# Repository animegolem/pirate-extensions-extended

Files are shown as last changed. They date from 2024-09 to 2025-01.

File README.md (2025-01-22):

 # pirate-extensions-extended
Adapting AudioGroupCologne's Adaptions to the PIRATE In-Ear Microphones for electret micorphones and general headphone hobbyist use.

## Description
This repository contains additional supplementary materials for adapted in-ear microphones [1], based on the PIRATE microphones design by Denk et al. [2]

I strongly recommend reading both linked papers because this is just boiling down and stealing that work. o7 

## Contents

[Bill of Materials](Bill_of_Materials.md)

[Build Instructions](build_guide.md)

[Pirate Models](pirate-models)

The updated molds and guide tool support 3mm and 4mm electret capsules. Additionally, the original pirate extensions support a 3mm MEMS microphone. Note that only the top mold has been updated and the original center and base mold are still required. 

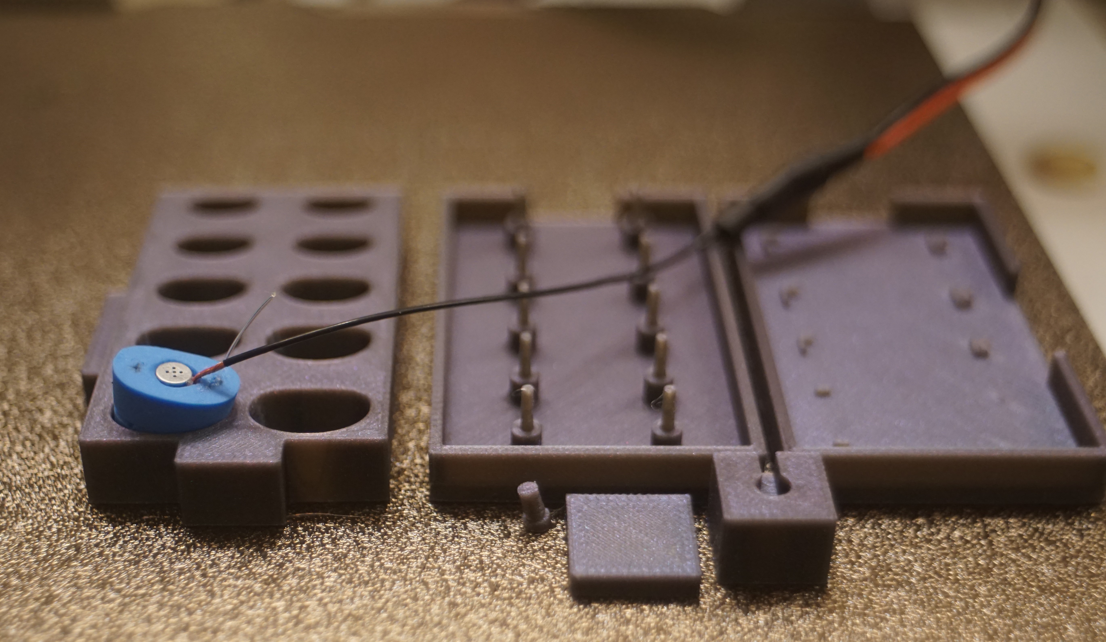
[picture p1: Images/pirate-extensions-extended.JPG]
4mm electret


For a rough guide on how to use the microphones and create a personal target please see the [usage guide](usage_guide/usage_guide.md). Please expect the results to be confusing and problematic if you start this project. 

I've also setup a [graphtool](https://animegolem.github.io/) as an example of how this data may look once collected. This data should not be compared to any other rig and extreme caution should be used when drawing any conclusions. 

## REFERENCES

[1] D. Bau, O. Moschner, C. Poerschmann "Adapting the PIRATE Design for Cost-Effective In-Ear Microphones", Proceedings of the 50th DAGA, Hannover, Mar. 2024

[2] F. Denk, F. Brinkmann, A. Stirnemann, and B. Kollmeier, “The PIRATE: an anthropometric earPlug with exchangeable microphones for Individual Reliable Acquisition of Transfer functions at the Ear canal entrance”, Proceedings of the 45th DAGA, Rostock, Mar. 2019

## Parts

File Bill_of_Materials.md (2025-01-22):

## Bill of Materials 

### Ear Plugs 

1. A reasonably competent 3D printer is required in order to create the mold. Alternatively you could use a print service. 

2. A two part, kneadable silicone. This should be between shore 40-65a so it is soft enough to form a perfect seal but firm enough that it will not deform and vary placement. The original paper suggests 55A is ideal if possible.

* [I've successfully used the following (40a) but harder would be more ideal.](https://www.amazon.com/dp/B09TGKS4KY)

* [Needs to be tested but likely better. (50a)](https://micromark.com/products/micro-mark-rtv-silicone-mold-putty-50-hard)

3. Monofilament fishing line, .4mm or greater.

4. Super Glue

5. A needle or similar to make holes in the finished plug

6. Straight razor to clean up demolded plug. 
 
### Microphone

1. 3-10ft Well shielded Microphone cable (I've used Canare L-2T2S)

2. Shrink Wrap or Electrical Tape 

3. 3mm/4mm Electret or 3mm MEMS microphone with a relatively flat and extended response. 

* see [capsule_testing](capsule_testing.md).

3. Male 3.5mm connector

4. 2 Part Epoxy or Thick Gel Super Glue
    
5. Apple dongle or equivalent

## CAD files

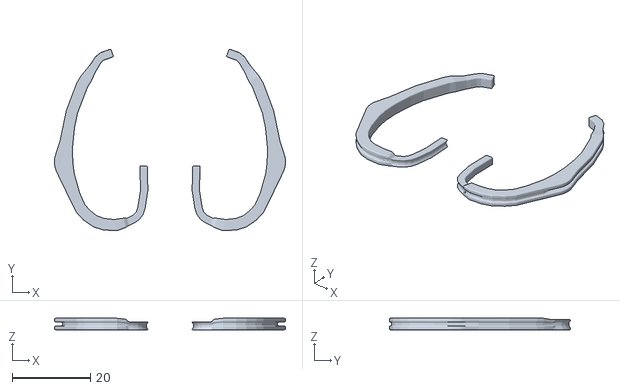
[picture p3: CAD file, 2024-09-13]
pirate-models/original-pirate-extensions/earhooks/earhooks_large.stl
59.1 x 46.4 x 2.95

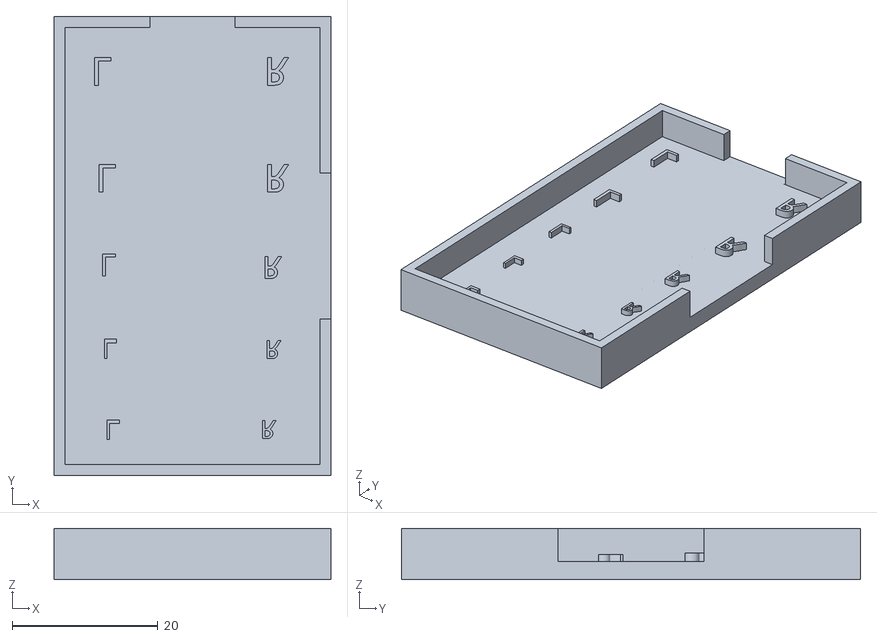
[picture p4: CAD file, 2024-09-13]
pirate-models/original-pirate-extensions/molds/pirate_form_bottom.stl
38.0 x 63.0 x 7.00

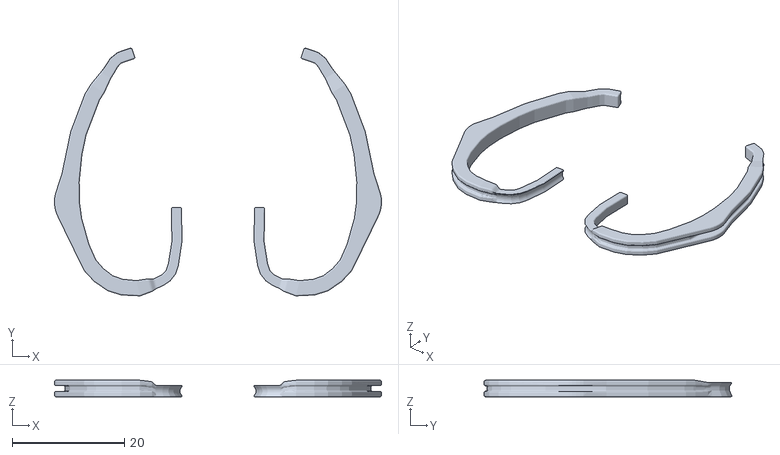
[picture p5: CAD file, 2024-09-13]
pirate-models/original-pirate-extensions/earhooks/earhooks_medium.stl
58.2 x 44.1 x 2.95

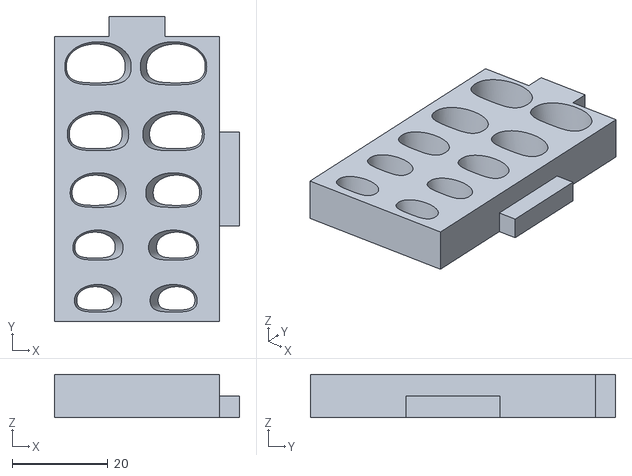
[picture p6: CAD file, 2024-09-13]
pirate-models/original-pirate-extensions/molds/pirate_form_middle.stl
38.8 x 63.8 x 9.00

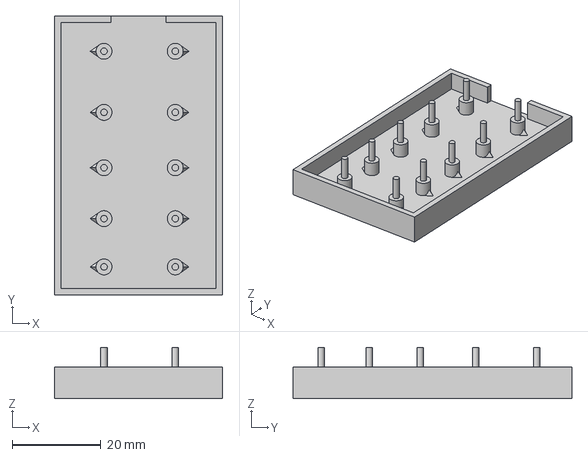
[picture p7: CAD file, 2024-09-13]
pirate-models/pirate_form_top_electret.step
38.0 x 63.0 x 11.6 mm

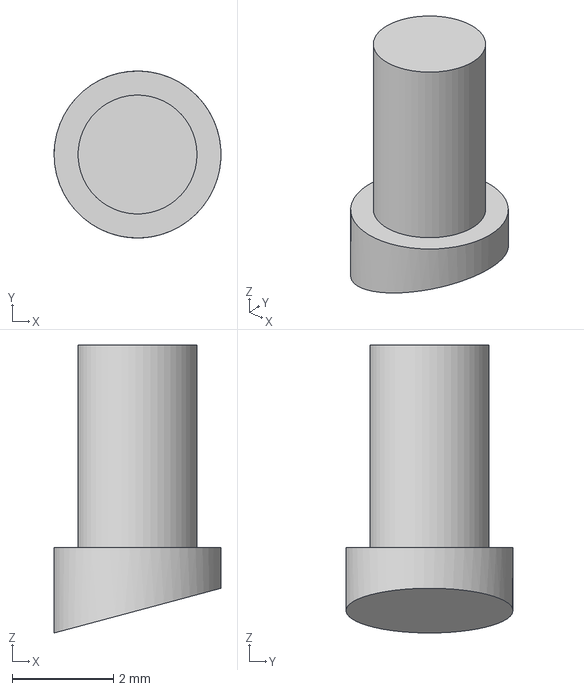
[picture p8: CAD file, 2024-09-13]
pirate-models/Electret Standoff -15% Tilt.step
3.30 x 3.30 x 5.69 mm

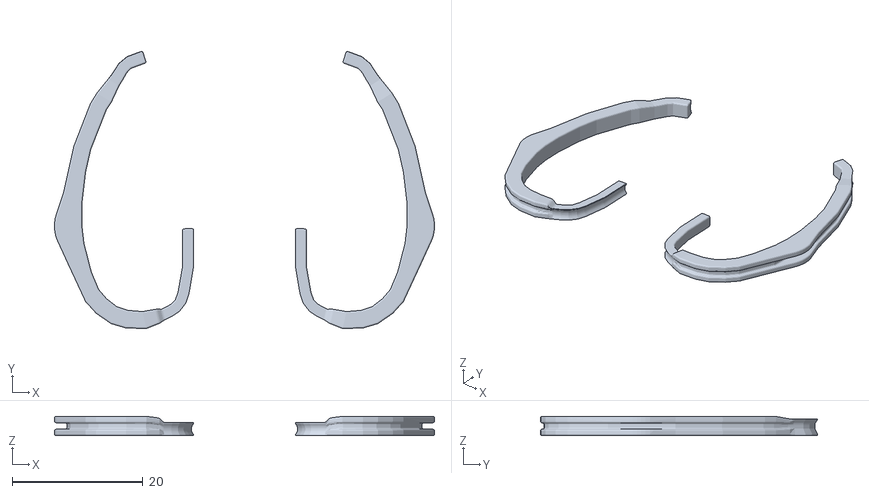
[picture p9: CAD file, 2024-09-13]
pirate-models/original-pirate-extensions/earhooks/earhooks_small.stl
58.1 x 42.3 x 2.95

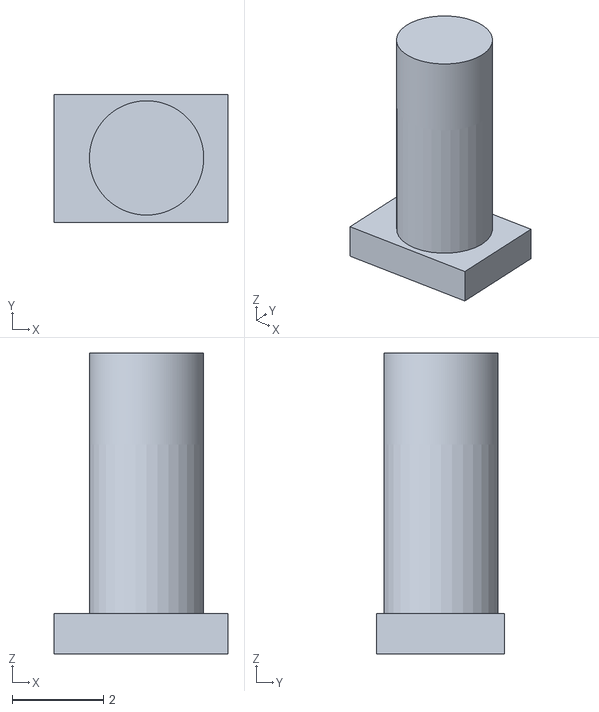
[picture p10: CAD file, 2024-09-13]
pirate-models/original-pirate-extensions/molds/pirate_mems_holder.stl
3.80 x 2.80 x 6.59

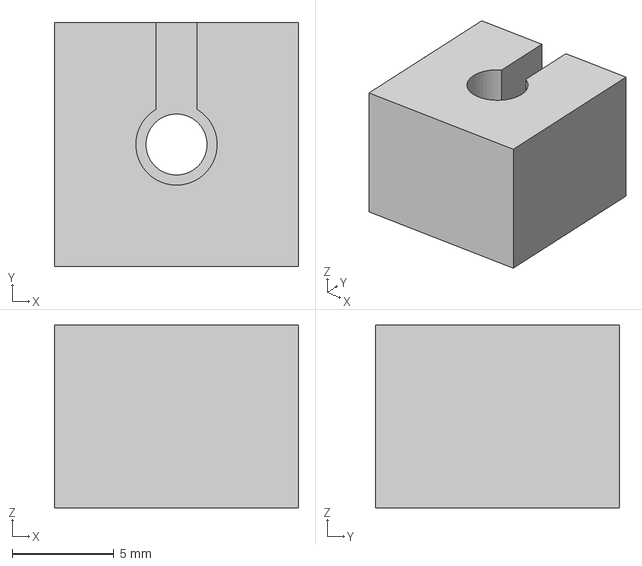
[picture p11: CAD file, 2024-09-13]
pirate-models/Gluing Guide Tool - Base.step
12.0 x 12.0 x 9.00 mm

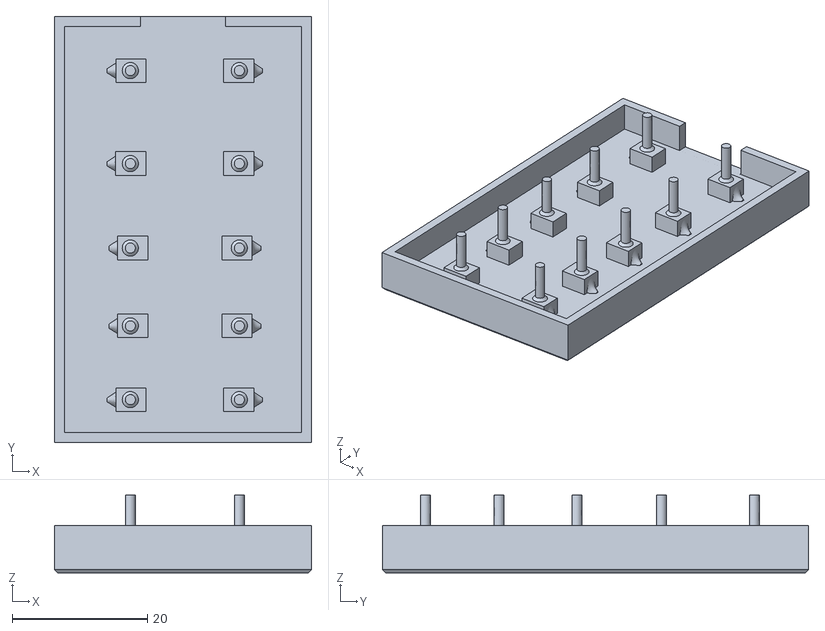
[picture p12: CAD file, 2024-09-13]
pirate-models/original-pirate-extensions/molds/pirate_form_top_mems.stl
38.0 x 63.0 x 11.5

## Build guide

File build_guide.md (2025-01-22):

# Ear Plugs

The molds create a 3.5mm hole for the microphone, in my experience this allowed both a 3mm and a 4mm electret without modification. If you find the 4mm mold too tight it should be safe to slightly increase the print scale of the **top mold** only. 

1. Print the universal base, middle, and appropriate top mold based on the capsule you have chosen to use. Any filament should work but petg or nylon will be less likely to snap when demolding. Using a .08mm or smaller layer height may help if you have issues printing the pegs. 
2. Using a 2-Part kneadable silicone combine enough material to fill the mold. In my experience roughly 7 grams of each reagent is more than sufficient. Ensure mold is filled as tightly as possible. 
3. Carefully demold. You will likely have to trim excess with a razor. You want plugs that are completely smooth and have no overhang past the mold.  
4. Using a needle or similar make a hole from top to bottom on the plug above and below the electret. The top hole is a vent to release pressure and should be unobstructed. The bottom hole should be filled with superglue and a piece of .4mm monofilament. Cut this at a length you can safely pull from the ear without yanking on the microphone leads. Generally 1-2cm should be sufficient.
5. Using something flat like a allen key push out a hole below the microphone standoff. This will be sealed during use but allow you to easily push out and remove the capsule without pulling the leads.

pirate molds

I do not advise using the ear hooks as the original shape of the plugs is designed around the strain relief being oriented down from the ear. 

# Microphone
The Microphone must be glued to a standoff in order to be held in the earplug. This should be done using a 2 part epoxy or super glue. The provided guide tool was designed with a 3mm electret originally but can be used with a 4mm if you increase the print scale to around 100.5. 

Guide Tool

The actual microphone is very simple to construct. From the capsule bridge hot to both internal wires. On the TRS solder to either tip or bridge ring and tip if you'd like an output on both channels. It shouldn't really make a difference either way. Use the sheathing as ground. Use shrink wrap over solder joints.  

The shielded Canare cables are quite thick and you may want to run a thinner wire for a few inches up to the capsule to make the cable more manageable. 

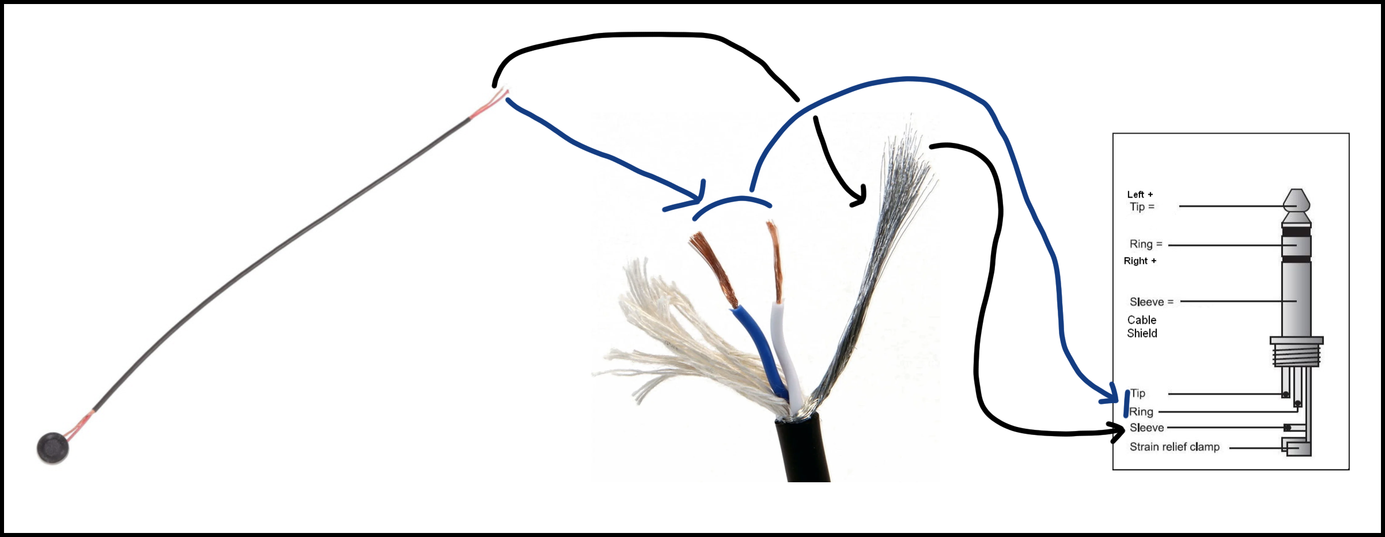
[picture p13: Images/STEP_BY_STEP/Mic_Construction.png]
wiring


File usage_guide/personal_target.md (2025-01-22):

Very roughly, 

1. Take a long moving mic measurement of a single speaker with good directivity. This is using a measurement microphone, not your DIY PIRATE.  
2. Very strictly EQ the speaker to flat. Limit your measuring position very tightly, only slightly larger than the expected space of your own head as you rotate and look up and down. If possible consider hanging a marker above the intended listening position. 

*You may have the best luck by creating a Equalizer APO graphic EQ via AutoEQ which functionally is the same as a convolution filter. You will likely need to raise Max Gain and Max Slope quite substantially, on the order of 75/35.*

3. Remeasure the speaker to validate the eq results. Ideally remeasure using the capsule to validate the calibration.     
4. Enable the generator in REW and calibrate the capsule mic while in ear using an external SPL meter.
5. In a rotating chair take a moving mic measurement. Aim to move slowly and evenly while looking fully up and down from all positions while repeatedly rotating 360. Repeat this until the measurement has become stable, likely in the range of 600-1000 avgs.
6. Repeat for the second ear. Your ears are not identical and while they should broadly track you should not expect them to be identical. Take an average of both results. 
7. Using the EQ window in REW find the best point of agreement around 2khz against one of the targets provided on my [graphtool](https://animegolem.github.io/). Remember to remove any adjustments.
8. Smooth as required and merge the results. 

I recommend standing up your own instance of Haruto's [PublicGraphTool](https://github.com/HarutoHiroki/PublicGraphTool) since the tilts and Harman filters are *incredibly* useful in finding your preference. It's a pain in ass but if you're already this far down the hole  ¯\_(ツ)_/¯

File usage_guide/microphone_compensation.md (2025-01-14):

Very broadly in REW; 

1. Measure a single speaker with a long moving mic measurement using a measurement mic.
2. Repeat using the capsule. Match position as closely as possible. It may be helpful to hang a marker, you want to limit it to barely larger than the size of your head. 
3. Select each measurement alone and take an RMS avg. The resulting measurement will get the prefix "Magn" to show it's magnitude only. 
4. Select arithmetic and divide A/B with the Uncalibrated Mic over the Calibrated Mic. Consider adjusting the boundaries in the trace arithmetic window based on speaker roll off, e.g. the speaker rolls off at 60hz and you cut off everything below this. 
5. Save with a 20,20k cut off and 1/3rd-1/6th smoothing.

This calibration file can now be applied in REW under Preferences ---> Cal Files.

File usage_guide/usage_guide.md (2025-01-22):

It's important to understand going in that In-Ear Mics are finnicky and complicated, while your measured result will likely be a *very* good starting point some work will still be required to understand your preferences and any issues in your specific measurement setup. Additionally blocked canal mics will not pick up any canal effects and you should expect notable variation from 1-3k in particular. 

Some familiarity with basic audio science concepts is likely required to use these mics and is well beyond the scope of this guide. Read the original papers and proceed with caution. 

The basic steps required are as follows; 

1. [Create a compensation file for the electret capsule.](microphone_compensation.md) 

2. [Create your personal DF HRTF target.](personal_target.md) This is the preferred but significantly more complicated option. It will also requires a speaker with sufficient directivity to be EQ'd flat in the listening position.
   
      or

3. EQ using the "ISO 11904" or "ARI, HUTUBS, RIEC, SONICOM AV" targets. This should be more than sufficient to improve in-situ bass response and midrange up to 1-2k. The treble may vary more widely but in practice this should be similar to EQing using rig results. Since you are capturing the correct HPTF effects you will likely find your results more repeatable from headphone to headphone, however. 

4. Measure headphones with compensation file in place. Your results will only be comparable to other measurements taken in your ear, with the same cal file, with the same microphone. 

If you do not wish to stand up your own graphtool the best option will be be using [Listener's Playground](https://listener800.github.io/eqplayground) or my [graphtool](https://animegolem.github.io/)

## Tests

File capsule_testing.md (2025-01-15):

# TOM-1537L-HD-LW100-B-R

Current Recomendation 

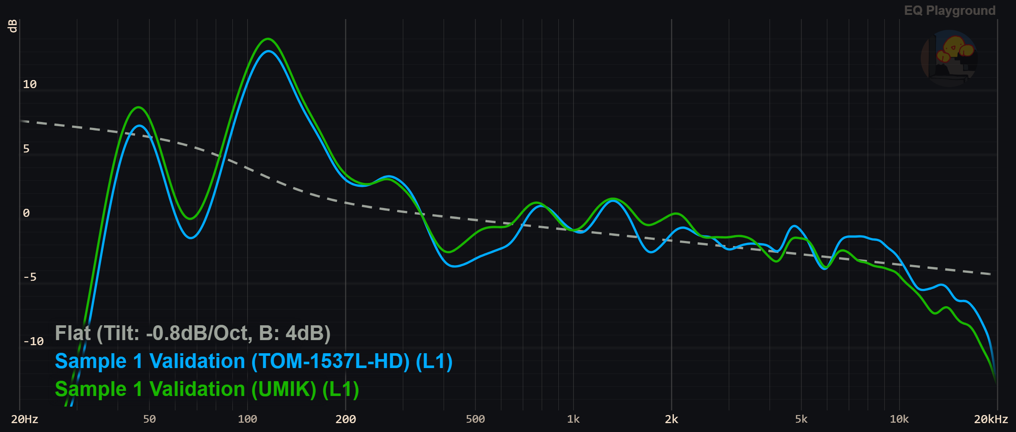
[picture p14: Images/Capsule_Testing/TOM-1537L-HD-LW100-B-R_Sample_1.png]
sample 1


# HBO0302C-58/1248

Sample 1 was problematic and showed massively increased LF roll off when in an ear. The mics are delicate and I've seen multiple die with no obvious cause.  

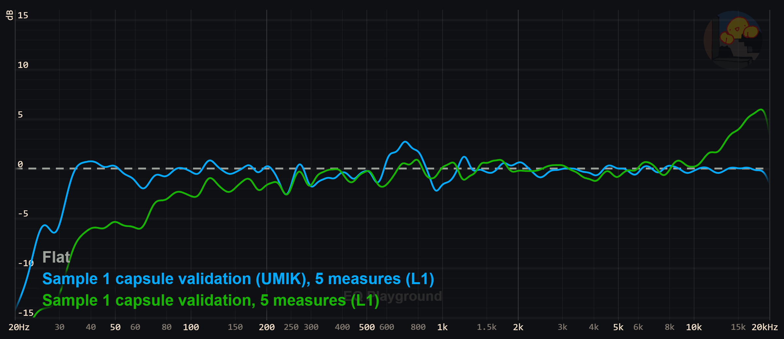
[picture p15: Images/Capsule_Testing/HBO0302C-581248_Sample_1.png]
sample 1


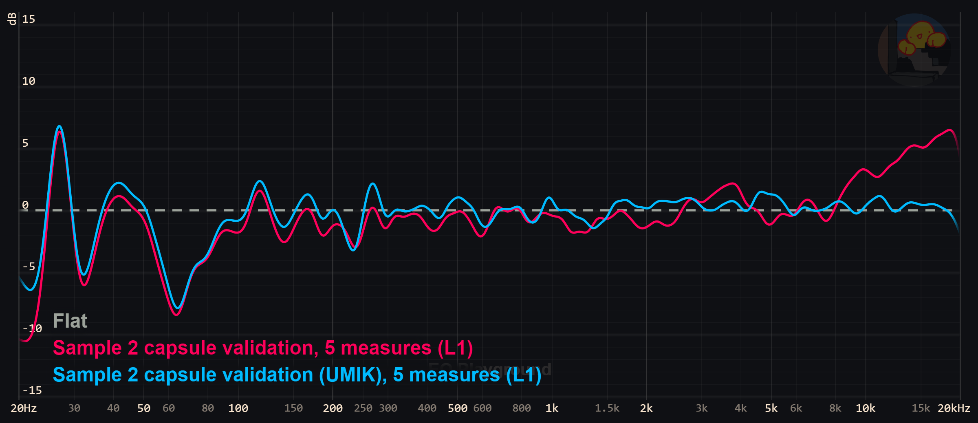
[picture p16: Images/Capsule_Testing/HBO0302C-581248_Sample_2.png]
sample 2


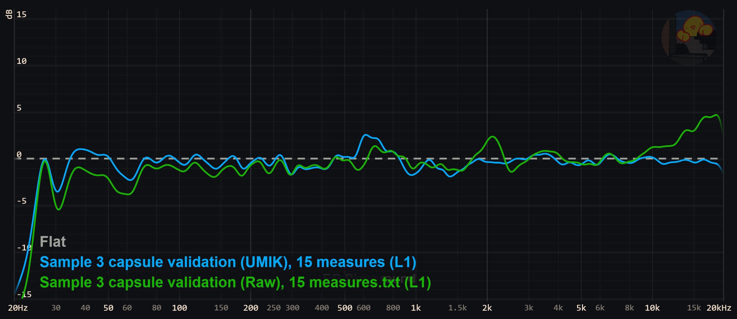
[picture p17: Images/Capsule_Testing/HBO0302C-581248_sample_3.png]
sample 3


# CMC-3015-44L100

Very problematic mains hum. Generally poor linearity. 

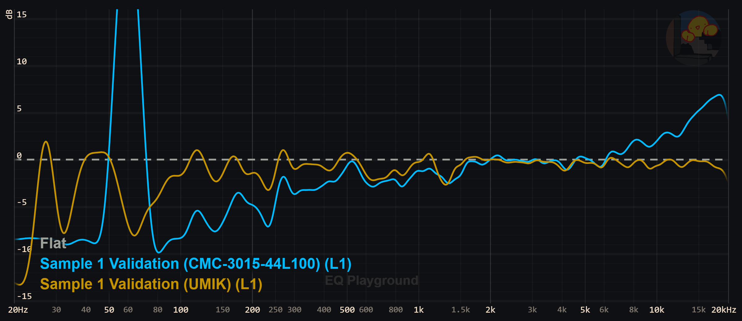
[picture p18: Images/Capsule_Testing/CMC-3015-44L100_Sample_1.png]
Sample 1


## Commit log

2024-09-13 Rename Bill of Materials.md to Bill _of_Materials.md
2025-01-22 Rename Gluing Guide Tool - Base - 3mm Electret.step to Gluing Guide Tool - Base.step
    [Gluing Guide Tool - Base.step]
2025-01-22 Rename 3mm Electret Top Mold.step to Electret Top Mold.step
    [Electret Top Mold.step]
2025-01-22 Rename 3mm Electret Standoff -15% Tilt.step to Electret Standoff -15% Tilt.step
    [Electret Standoff -15% Tilt.step]
2025-01-22 Rename Electret Top Mold.step to pirate_form_top_electret.step
    [pirate_form_top_electret.step]
